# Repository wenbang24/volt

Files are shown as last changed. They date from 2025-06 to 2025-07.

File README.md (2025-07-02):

# Volt
A portable guitar amp that works with your bluetooth device, so you can play anywhere, anytime.

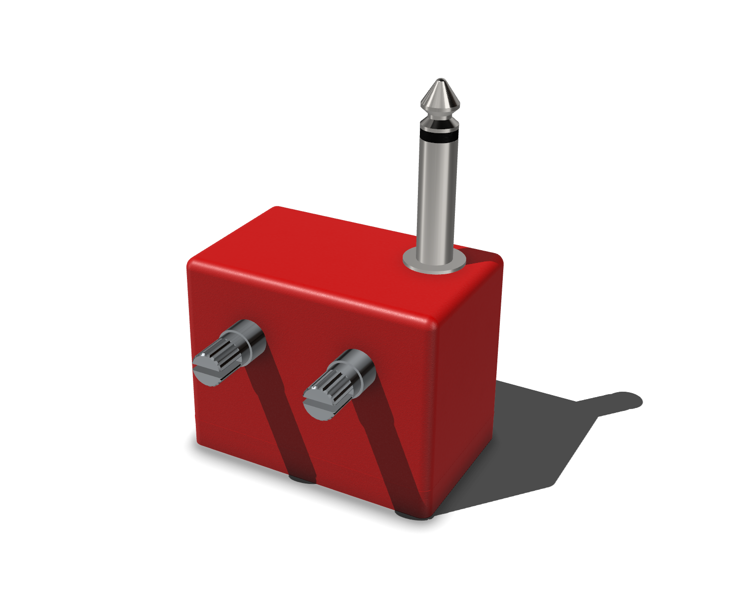
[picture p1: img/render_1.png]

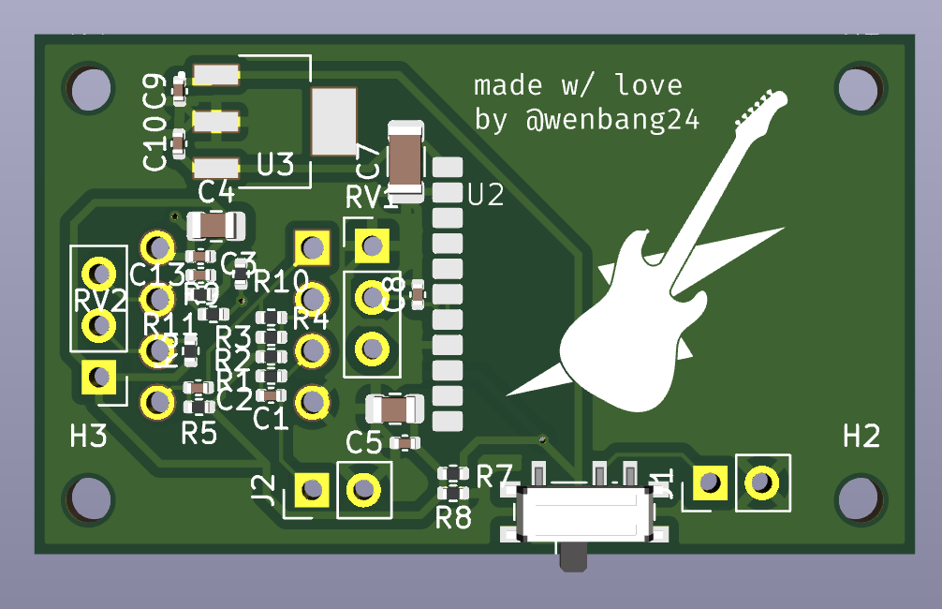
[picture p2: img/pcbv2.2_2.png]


## BOM
|Designator |Footprint |Quantity|Value |LCSC Part #| Link |
|---|---|---|---|---|---|
|C1, C13 |0402 |2 |1u |C14445 |[LCSC](https://lcsc.com/product-detail/Multilayer-Ceramic-Capacitors-MLCC-SMD-SMT_Samsung-Electro-Mechanics-CL05A105KP5NNNC_C14445.html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)|
|C10, C3, C5 |0402 |3 |100n |C1525 |[LCSC](https://lcsc.com/product-detail/Multilayer-Ceramic-Capacitors-MLCC-SMD-SMT_Samsung-Electro-Mechanics-CL05B104KO5NNNC_C1525.html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)|
|C2, C8 |0402 |2 |4u7 |C23733 |[LCSC](https://lcsc.com/product-detail/Multilayer-Ceramic-Capacitors-MLCC-SMD-SMT_Samsung-Electro-Mechanics-CL05A475MP5NRNC_C23733.html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)|
|C4, C6 |0805 |2 |47u |C1954938 |[LCSC](https://lcsc.com/product-detail/Tantalum-Capacitors_Kyocera-AVX-TLJR476M010R3200_C1954938.html?s_z=n_C1954938)|
|C7 |1206 |1 |100u |C883598 |[LCSC](https://lcsc.com/product-detail/Multilayer-Ceramic-Capacitors-MLCC-SMD-SMT_Murata-Electronics-GRM31CR61A107MEA8L_C883598.html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)|
|C9 |0402 |1 |0.22u |C16772 |[LCSC](https://lcsc.com/product-detail/Multilayer-Ceramic-Capacitors-MLCC-SMD-SMT_Samsung-Electro-Mechanics-CL05B224KO5NNNC_C16772.html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)|
|R1 |0402 |1 |1k |C26083 |[LCSC](https://lcsc.com/product-detail/Chip-Resistor-Surface-Mount_UNI-ROYAL-Uniroyal-Elec-0402WGF1004TCE_C26083.html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)|
|R10, R3 |0402 |2 |4k7 |C25900 |[LCSC](https://lcsc.com/product-detail/Chip-Resistor-Surface-Mount_UNI-ROYAL-Uniroyal-Elec-0402WGF4701TCE_C25900.html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)|
|R11, R4, R6 |0402 |3 |10k |C25744 |[LCSC](https://lcsc.com/product-detail/Chip-Resistor-Surface-Mount_UNI-ROYAL-Uniroyal-Elec-0402WGF1002TCE_C25744.html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)|
|R2, R7, R8, R9|0402 |4 |100k |C25741 |[LCSC](https://lcsc.com/product-detail/Chip-Resistor-Surface-Mount_UNI-ROYAL-Uniroyal-Elec-0402WGF1003TCE_C25741.html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)|
|R5 |0402 |1 |220k |C25767 |[LCSC](https://lcsc.com/product-detail/Chip-Resistor-Surface-Mount_UNI-ROYAL-Uniroyal-Elec-0402WGF2203TCE_C25767.html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)|
|SW1 |SW_SPDT_PCM12 |1 |SW_SPDT |C221841 |[LCSC](https://lcsc.com/product-detail/Slide-Switches_C-K-PCM12SMTR_C221841.html?s_z=n_C221841)|
|U3 |VREG_LM7805MP_NOPB|1 |LM7805_TO220|C2848241 |[LCSC](https://lcsc.com/product-detail/Voltage-Regulators-Linear-Low-Drop-Out-LDO-Regulators_Texas-Instruments-LM7805MPX-NOPB_C2848241.html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)|

Price: $6.47
### Parts to source yourself
|Designator |Footprint |Quantity|Value | Link |
|---|---|---|---|---|
|U1|DIP-8|1|TL072|[AliExpress](https://www.aliexpress.com/item/1005006135219871.html?spm=a2g0o.order_list.order_list_main.17.5d4e1802HO5hMP)|
|U2||1|BT 5.3 Audio Transmitter|[AliExpress](https://www.aliexpress.com/item/1005006761214266.html?spm=a2g0o.order_list.order_list_main.35.5d4e1802HO5hMP)|
|J1||1|1/4" Audio Jack|[AliExpress](https://www.aliexpress.com/item/1005006199010497.html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)|
|J2||1|9V Battery Connector|[AliExpress](https://www.aliexpress.com/item/1005003688602261.html?spm=a2g0o.order_list.order_list_main.23.531a1802qO4r9D)|
|RV1||1|100k Potentiometer (logarithmic)|[Core Electronics](https://core-electronics.com.au/rotary-potentiometer-100k-ohm-logarithmic-panel-mount.html)|
|RV2||1|100k Potentiometer (linear)|[Core Electronics](https://core-electronics.com.au/rotary-potentiometer-100k-ohm-linear-panel-mount.html)|
|||4|M2 Screws|[AliExpress](https://www.aliexpress.com/item/4000970993800.html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)|

Price: $16.57

Also:
- 9V Battery
- Case (files in `case/`)
- Some wires & solder

Total PCB & PCBA Price: $32.51

Total Price: $49.08

**Total Price + est. shipping**: $60.00

(prices converted from AUD to USD, accurate as of 2025-06-29)

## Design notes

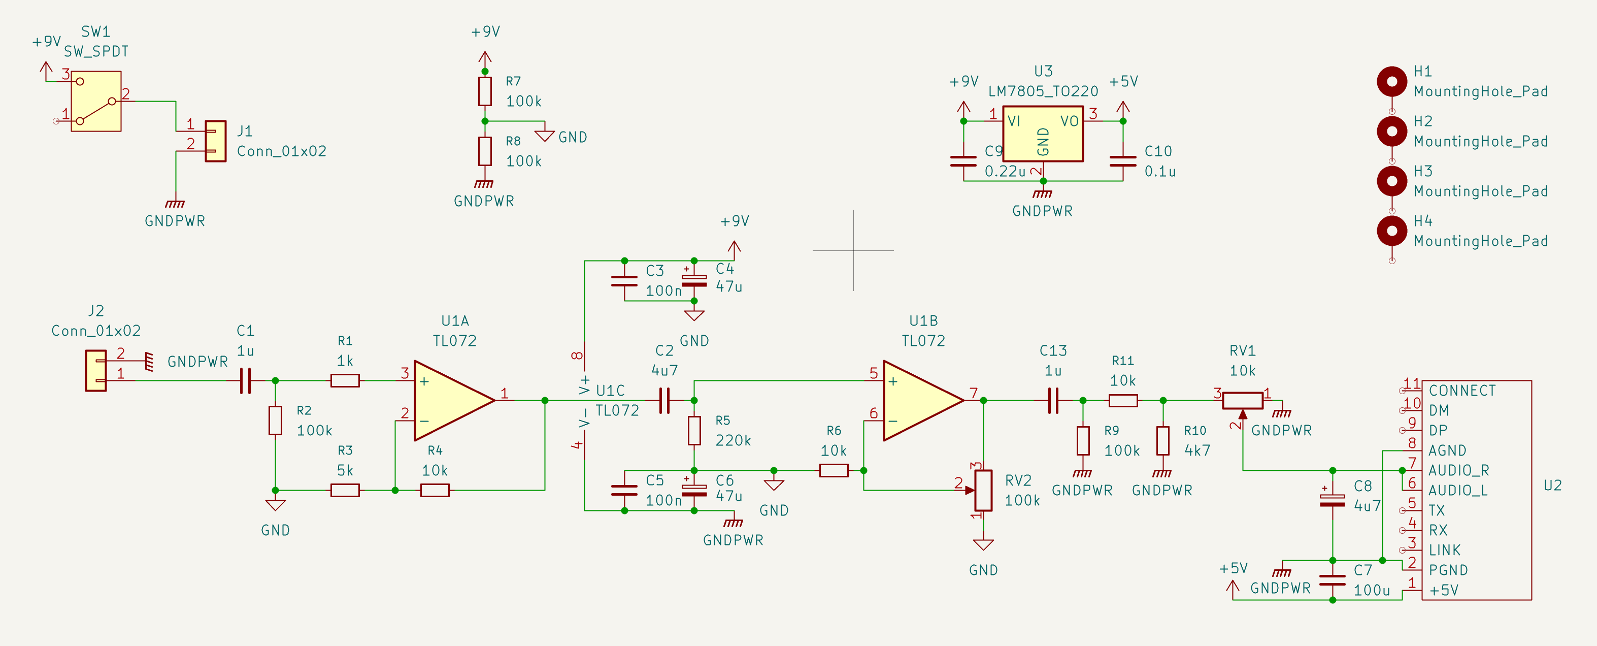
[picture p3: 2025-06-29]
img/schematicv3.png

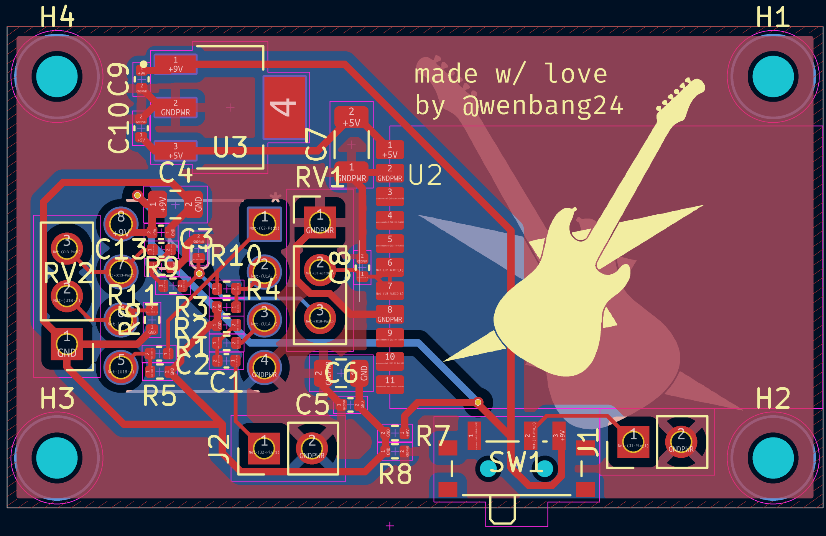
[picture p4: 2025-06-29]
img/pcbv2.2_3.png

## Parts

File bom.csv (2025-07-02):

Designator | Footprint | Quantity | Value | LCSC Part # | Link
C1, C13 | 0402 | 2 | 1u | C14445 | https://lcsc.com/product-detail/Multilayer-Ceramic-Capacitors-MLCC-SMD-SMT_Samsung-Electro-Mechanics-CL05A105KP5NNNC_C14445.html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
C10, C3, C5 | 0402 | 3 | 100n | C1525 | https://lcsc.com/product-detail/Multilayer-Ceramic-Capacitors-MLCC-SMD-SMT_Samsung-Electro-Mechanics-CL05B104KO5NNNC_C1525.html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
C2, C8 | 0402 | 2 | 4u7 | C23733 | https://lcsc.com/product-detail/Multilayer-Ceramic-Capacitors-MLCC-SMD-SMT_Samsung-Electro-Mechanics-CL05A475MP5NRNC_C23733.html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
C4, C6 | 0805 | 2 | 47u | C1954938 | https://lcsc.com/product-detail/Tantalum-Capacitors_Kyocera-AVX-TLJR476M010R3200_C1954938.html?s_z=n_C1954938
C7 | 1206 | 1 | 100u | C883598 | https://lcsc.com/product-detail/Multilayer-Ceramic-Capacitors-MLCC-SMD-SMT_Murata-Electronics-GRM31CR61A107MEA8L_C883598.html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
C9 | 0402 | 1 | 0.22u | C16772 | https://lcsc.com/product-detail/Multilayer-Ceramic-Capacitors-MLCC-SMD-SMT_Samsung-Electro-Mechanics-CL05B224KO5NNNC_C16772.html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
R1 | 0402 | 1 | 1k | C26083 | https://lcsc.com/product-detail/Chip-Resistor-Surface-Mount_UNI-ROYAL-Uniroyal-Elec-0402WGF1004TCE_C26083.html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
R10, R3 | 0402 | 2 | 4k7 | C25900 | https://lcsc.com/product-detail/Chip-Resistor-Surface-Mount_UNI-ROYAL-Uniroyal-Elec-0402WGF4701TCE_C25900.html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
R11, R4, R6 | 0402 | 3 | 10k | C25744 | https://lcsc.com/product-detail/Chip-Resistor-Surface-Mount_UNI-ROYAL-Uniroyal-Elec-0402WGF1002TCE_C25744.html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
R2, R7, R8, R9 | 0402 | 4 | 100k | C25741 | https://lcsc.com/product-detail/Chip-Resistor-Surface-Mount_UNI-ROYAL-Uniroyal-Elec-0402WGF1003TCE_C25741.html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
R5 | 0402 | 1 | 220k | C25767 | https://lcsc.com/product-detail/Chip-Resistor-Surface-Mount_UNI-ROYAL-Uniroyal-Elec-0402WGF2203TCE_C25767.html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
SW1 | SW_SPDT_PCM12 | 1 | SW_SPDT | C221841 | https://lcsc.com/product-detail/Slide-Switches_C-K-PCM12SMTR_C221841.html?s_z=n_C221841
U3 | VREG_LM7805MP_NOPB | 1 | LM7805_TO220 | C2848241 | https://lcsc.com/product-detail/Voltage-Regulators-Linear-Low-Drop-Out-LDO-Regulators_Texas-Instruments-LM7805MPX-NOPB_C2848241.html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
U1 | DIP-8 | 1 | TL072 |  | https://www.aliexpress.com/item/1005006135219871.html
U2 |  | 1 | BT 5.3 Audio Transmitter |  | https://www.aliexpress.com/item/1005006761214266.html
J1 |  | 1 | 1/4" Audio Jack |  | https://www.aliexpress.com/item/1005006199010497.html?sourceType=1
J2 |  | 1 | 9V Battery Connector |  | https://www.aliexpress.com/item/1005003688602261.html
RV1 |  | 1 | 100k Potentiometer (logarithmic) |  | https://core-electronics.com.au/rotary-potentiometer-100k-ohm-logarithmic-panel-mount.html
RV2 |  | 1 | 100k Potentiometer (linear) |  | https://core-electronics.com.au/rotary-potentiometer-100k-ohm-linear-panel-mount.html
 |  | 4 | M2 Screw |  | https://www.aliexpress.com/item/4000970993800.html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

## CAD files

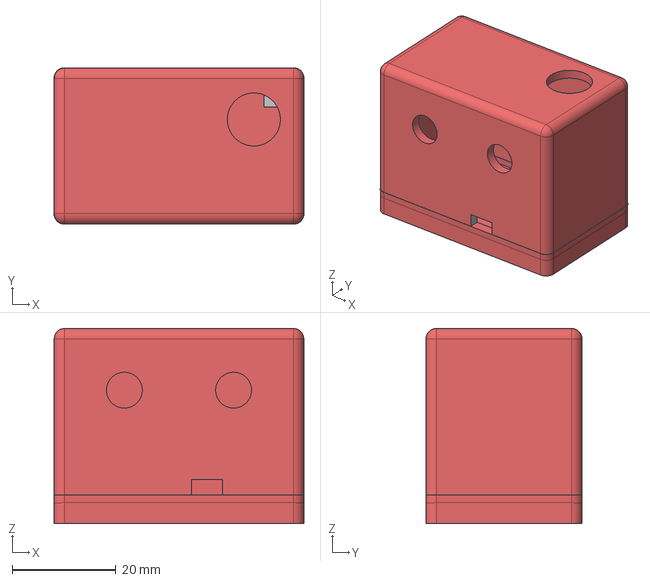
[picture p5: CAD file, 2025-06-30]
case/volt.step
48.1 x 30.1 x 37.5 mm

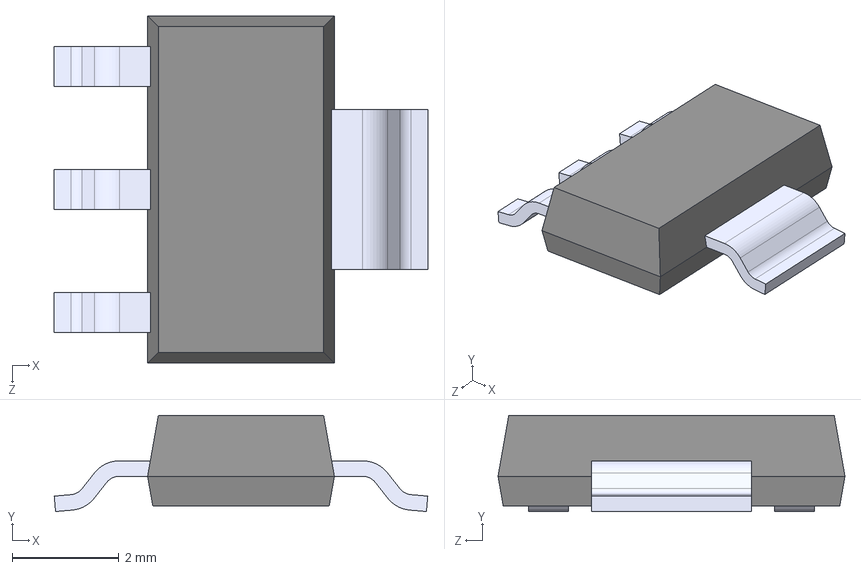
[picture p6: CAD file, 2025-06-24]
pcb/LM7805MP_NOPB/LM7805MP_NOPB.step
7.00 x 1.80 x 6.50 mm

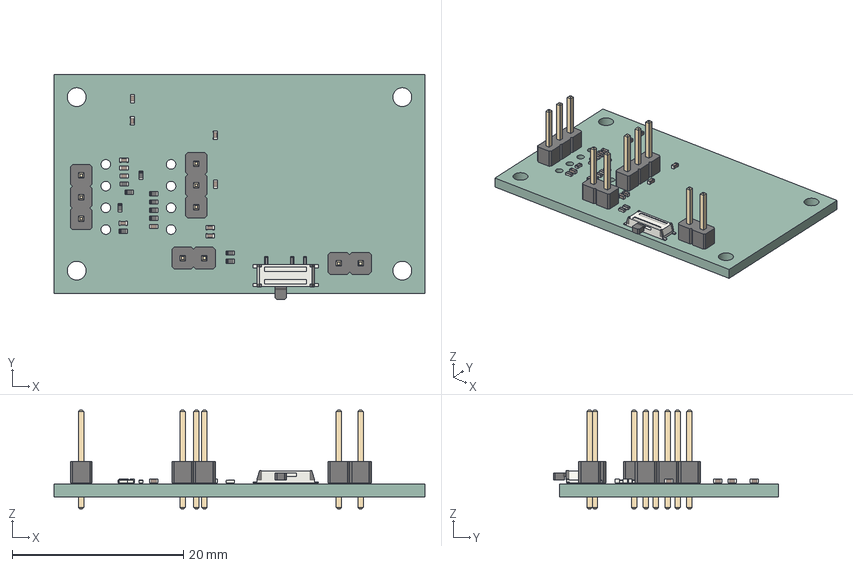
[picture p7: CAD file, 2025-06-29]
pcb/pcb.step
43.4 x 26.3 x 11.5 mm
C_0402_1005Metric x 11
R_0402_1005Metric x 11
PinHeader_1x03_P2.54mm_Vertical x 2
SW_SPDT_PCM12
PinHeader_1x02_P2.54mm_Vertical x 2
pcb_PCB

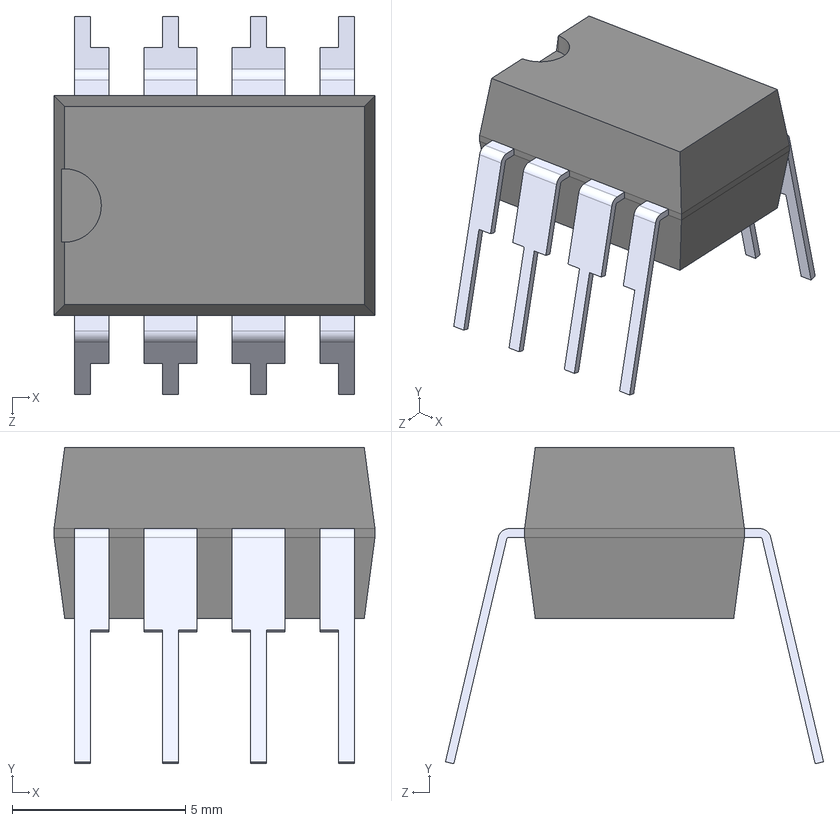
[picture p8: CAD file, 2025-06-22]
pcb/TL072CN/TL072CN.step
9.27 x 9.14 x 10.9 mm

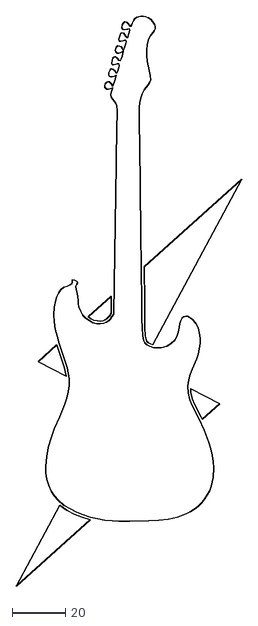
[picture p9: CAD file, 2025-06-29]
volt.dxf
84.9 x 215.1

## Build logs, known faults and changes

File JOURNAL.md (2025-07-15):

---
title: "Volt"
author: "Ben Wang"
description: "A bluetooth guitar amp for portable playing"
created_at: "2025-06-17"
---

total time (so far): 47.5 hrs

## 2025-06-17
- Researched how guitar amps work
- Researched components needed for a guitar amp
- Researched how bluetooth works

Time spent: 2 hrs

## 2025-06-18
- Found specific components to use
- Made symbols & footprints for the components
- Started researching how to make an amplifier circuit

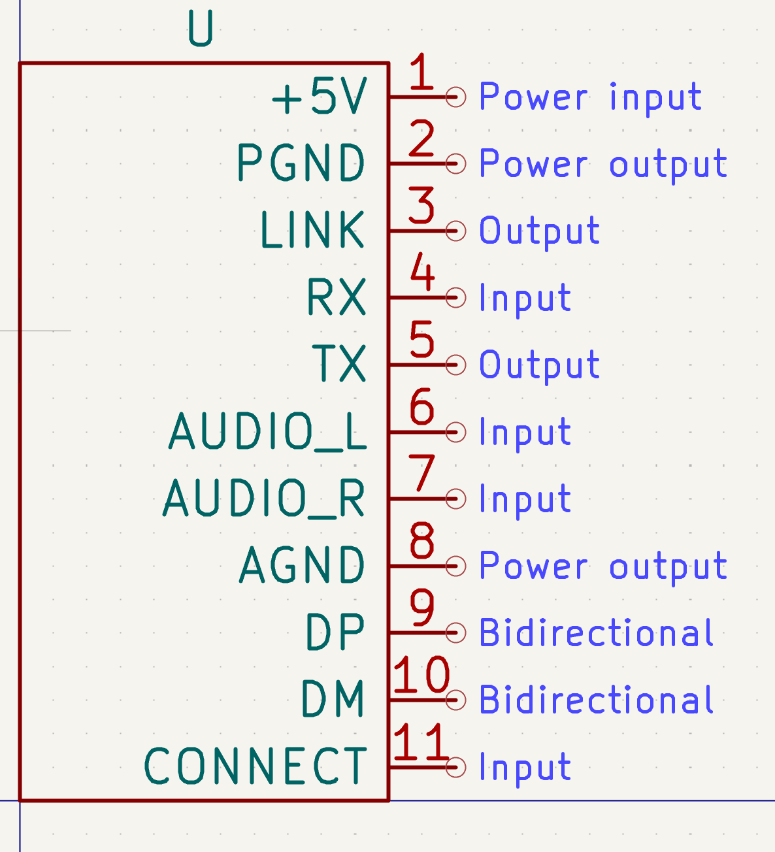
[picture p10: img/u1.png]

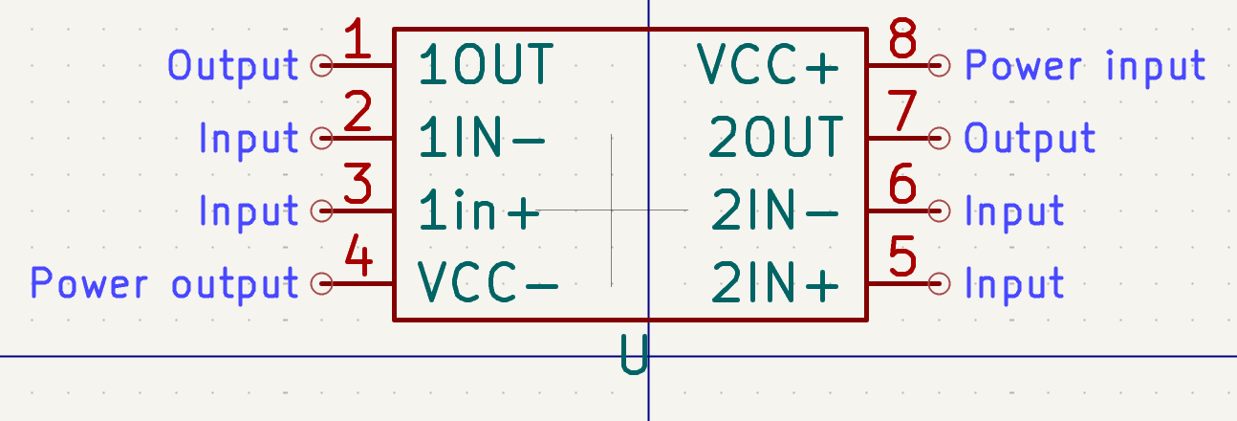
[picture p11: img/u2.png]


Time spent: 3 hrs

## 2025-06-21
- Fixed pin orientation of bluetooth module
- Made v1 of schematic (partial reference design [here](https://2.bp.blogspot.com/-1wqxx-jvaGM/V-nGi2WOsvI/AAAAAAAAA0s/gCCoJ27efYsKQ02fjROY2QzsP2jolWZbACLcB/s1600/HiFi%2BPreAmp%2BCircuit%2BSchematic.jpg))

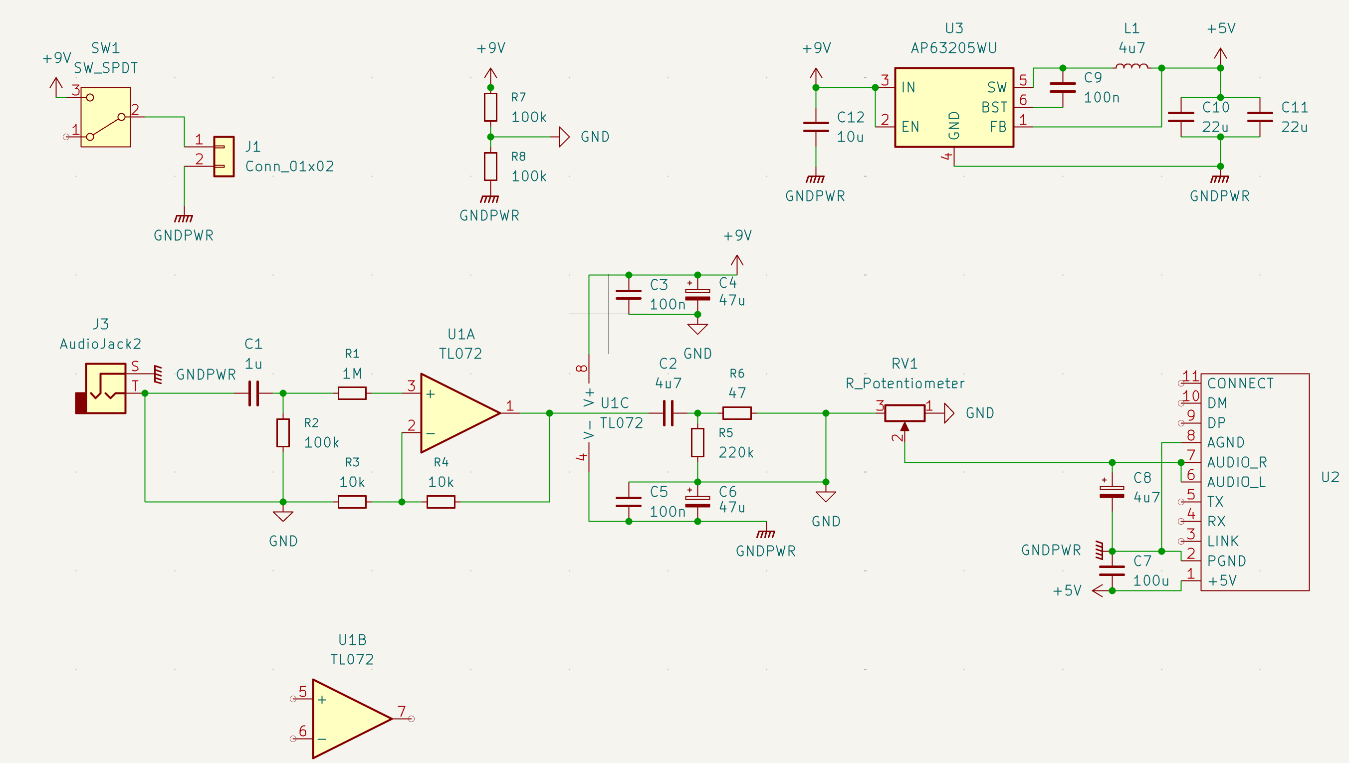
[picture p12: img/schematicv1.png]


Time spent: 7 hrs (yeah it was not easy :|)

## 2025-06-21
- Footprints, footprints, footprints
- First draft of PCB (awaiting review)
- Minor edits to schematic

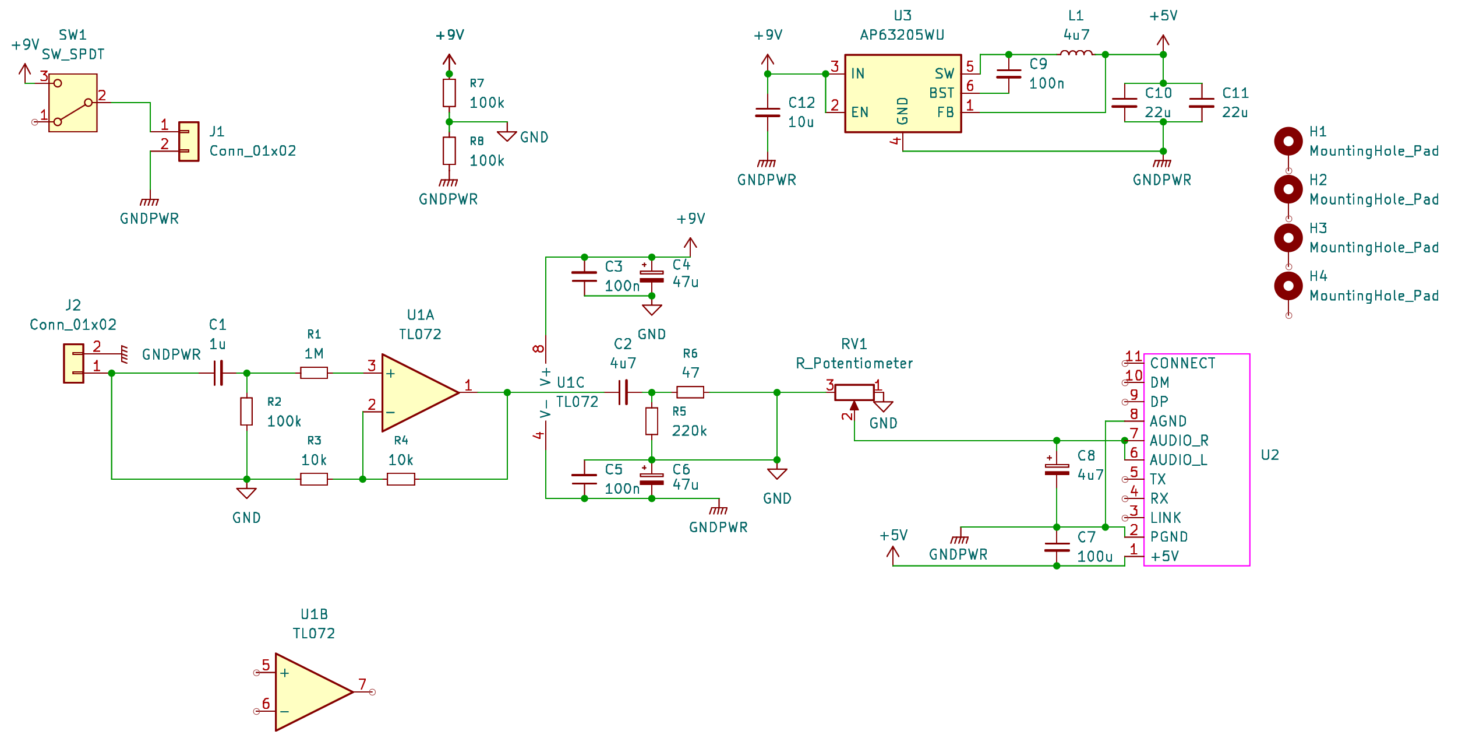
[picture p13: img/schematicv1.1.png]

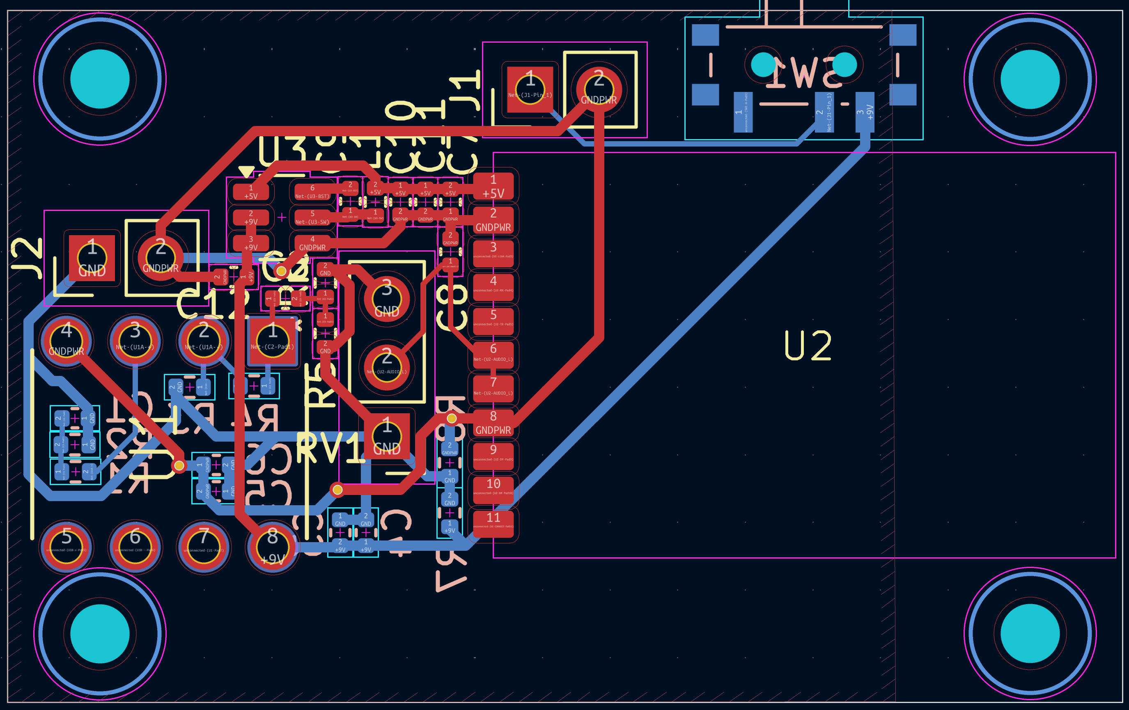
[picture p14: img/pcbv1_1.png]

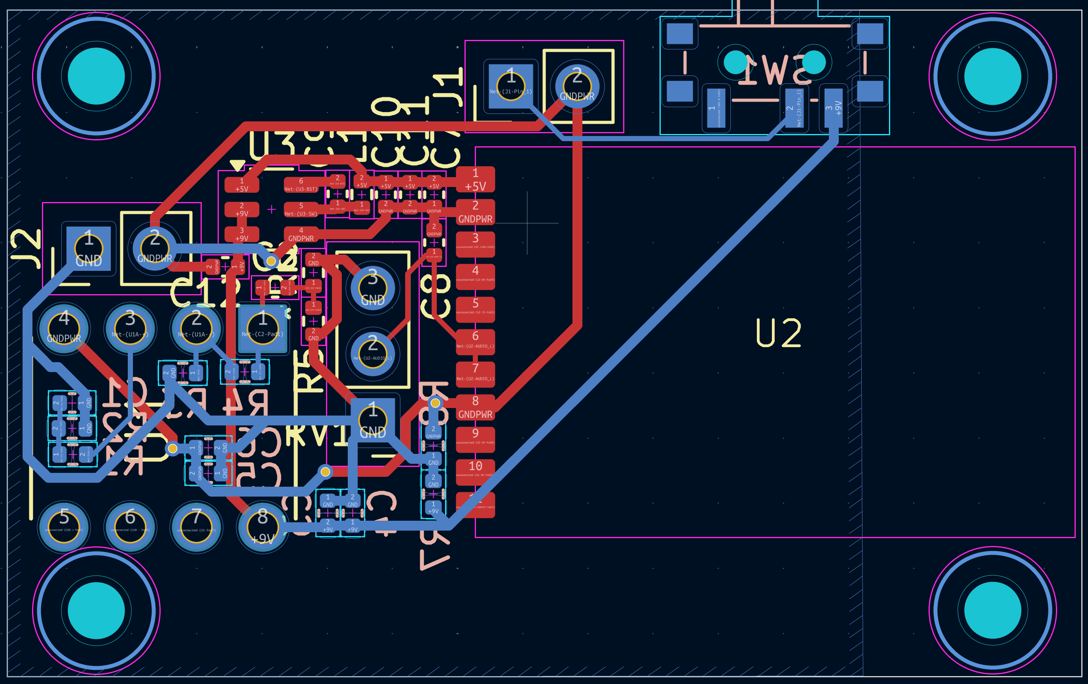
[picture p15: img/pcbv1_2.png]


Time spent: 5 hrs

## 2025-06-22
- Added distortion circuit
- Started figuring out how SPICE simulations work

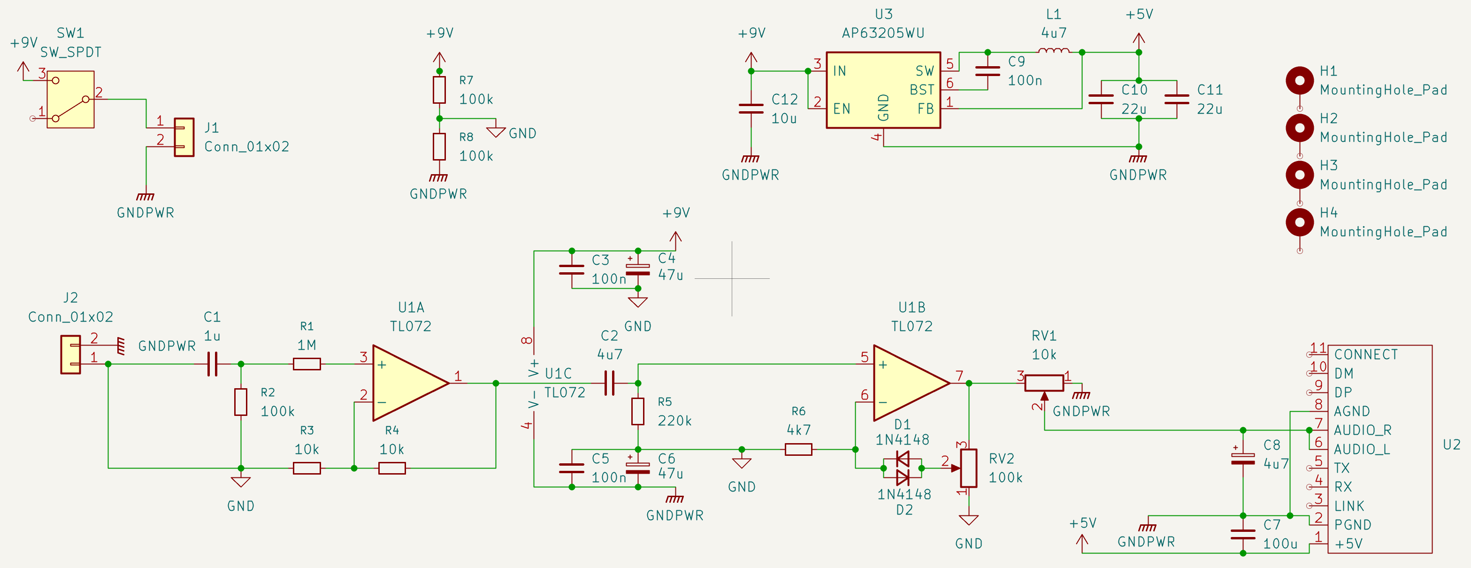
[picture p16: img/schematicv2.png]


Time spent: 4 hrs

## 2025-06-23
- Installed LTSpice
- Built the circuit in LTSpice
- Simulated the circuit
- Tried a lot of different values for the components
- Added an RC filter to the output
- Still not working :|

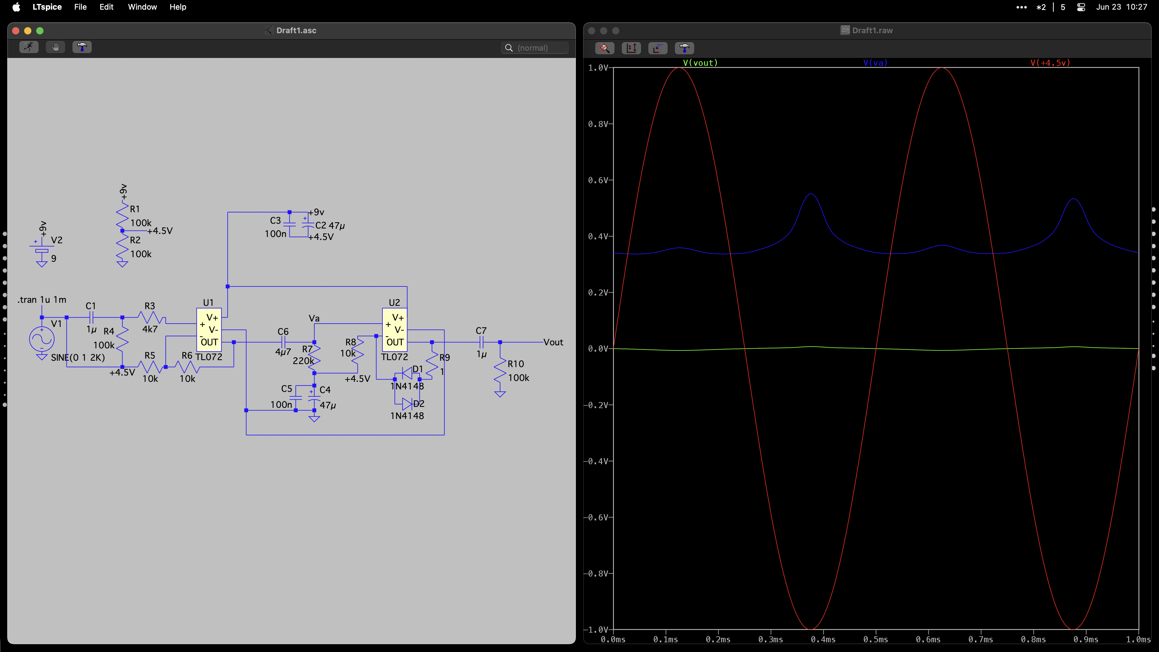
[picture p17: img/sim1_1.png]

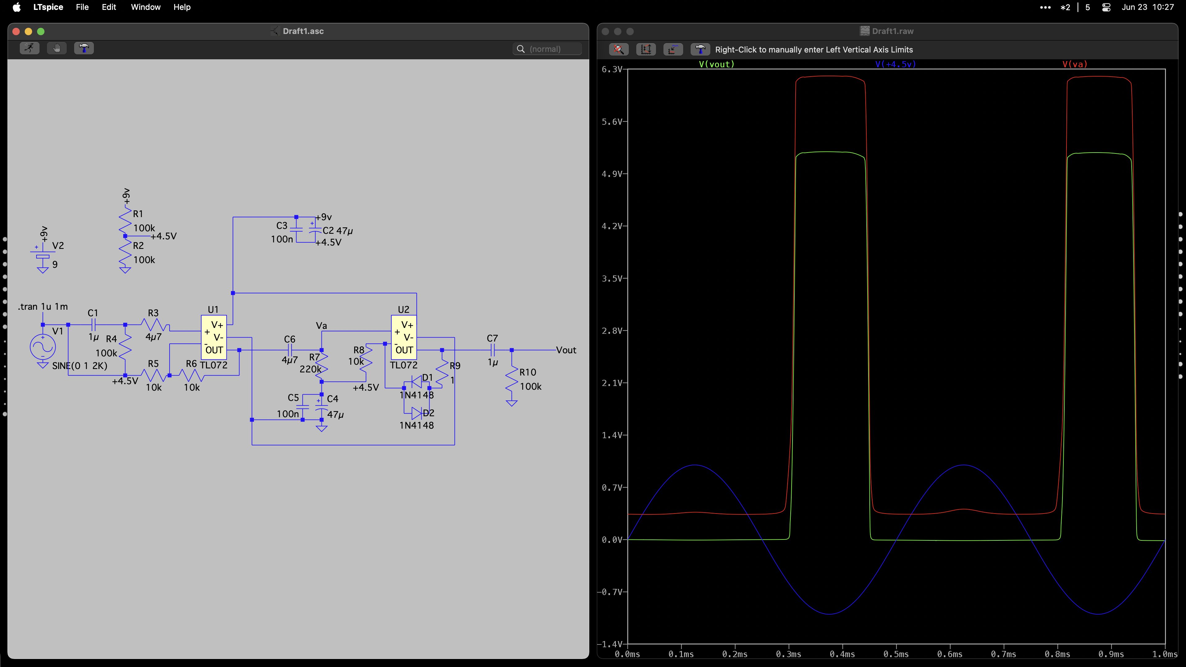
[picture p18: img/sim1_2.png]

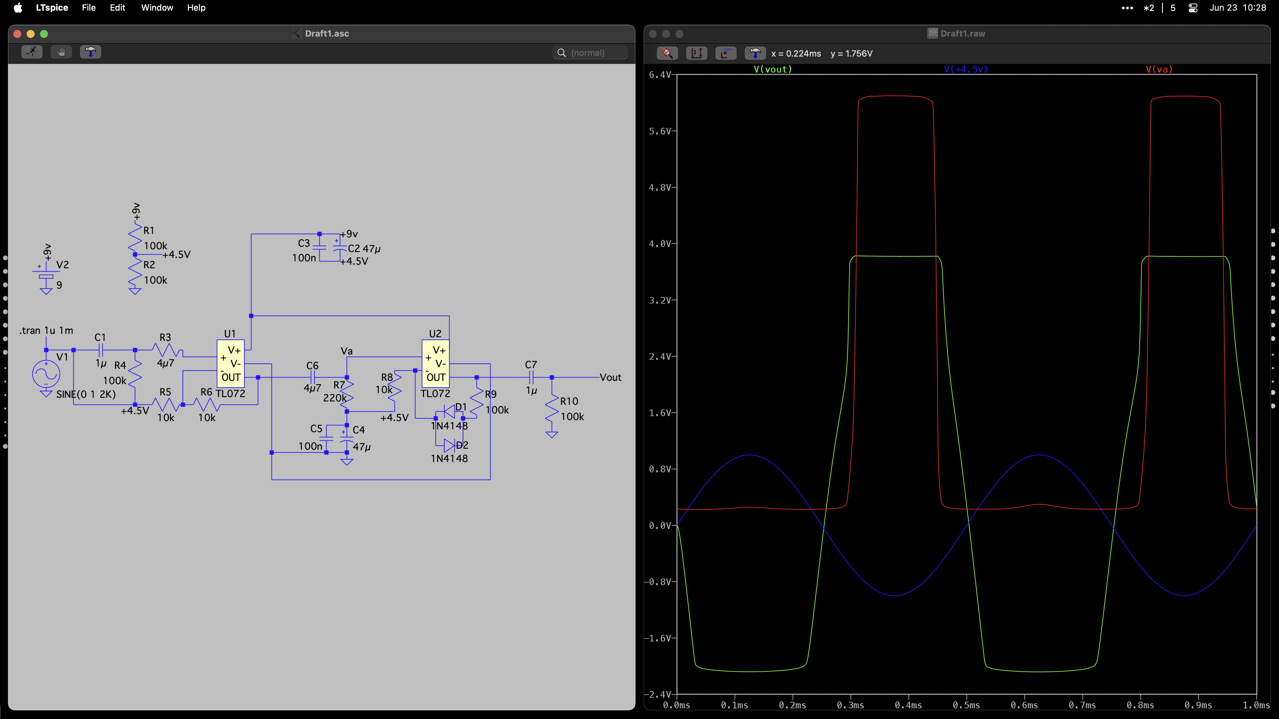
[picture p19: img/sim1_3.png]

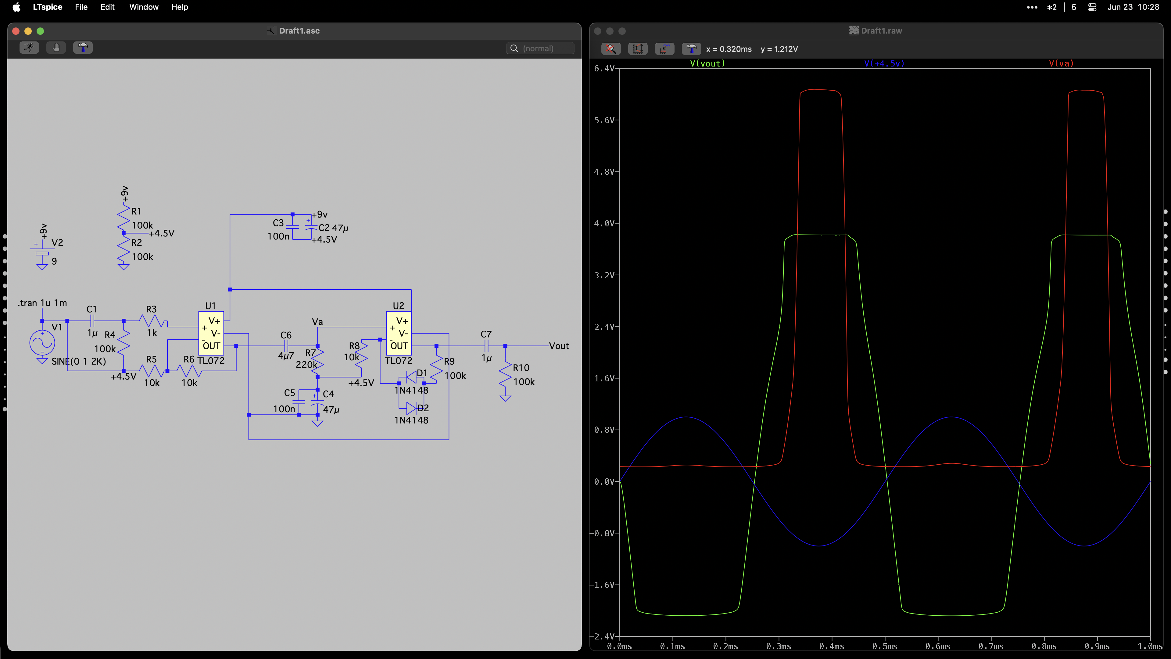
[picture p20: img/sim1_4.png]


Time spent: 6 hrs

## 2025-06-24
- Fixed distortion circuit
- Changed pre-amp stage
- Added voltage cap (max ~1.9VPP now)
- Changed to LDO for 9V to 5V conversion
- Rebuilt schematic in KiCad
- Researched some parts
- Added TRRS jack for headphone output

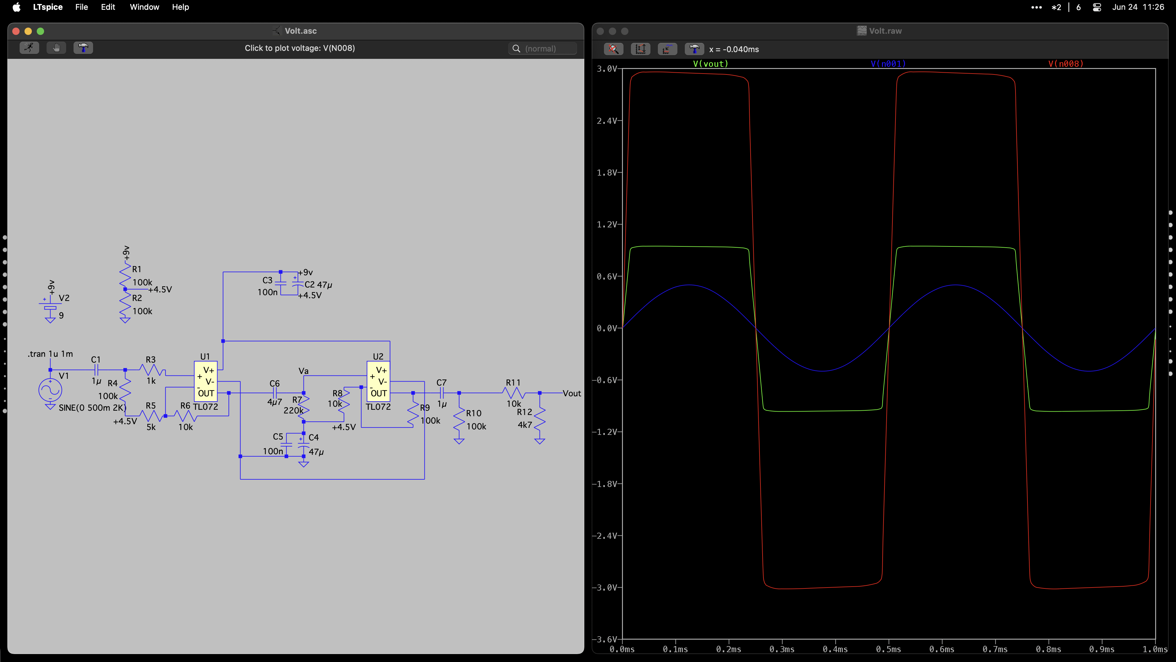
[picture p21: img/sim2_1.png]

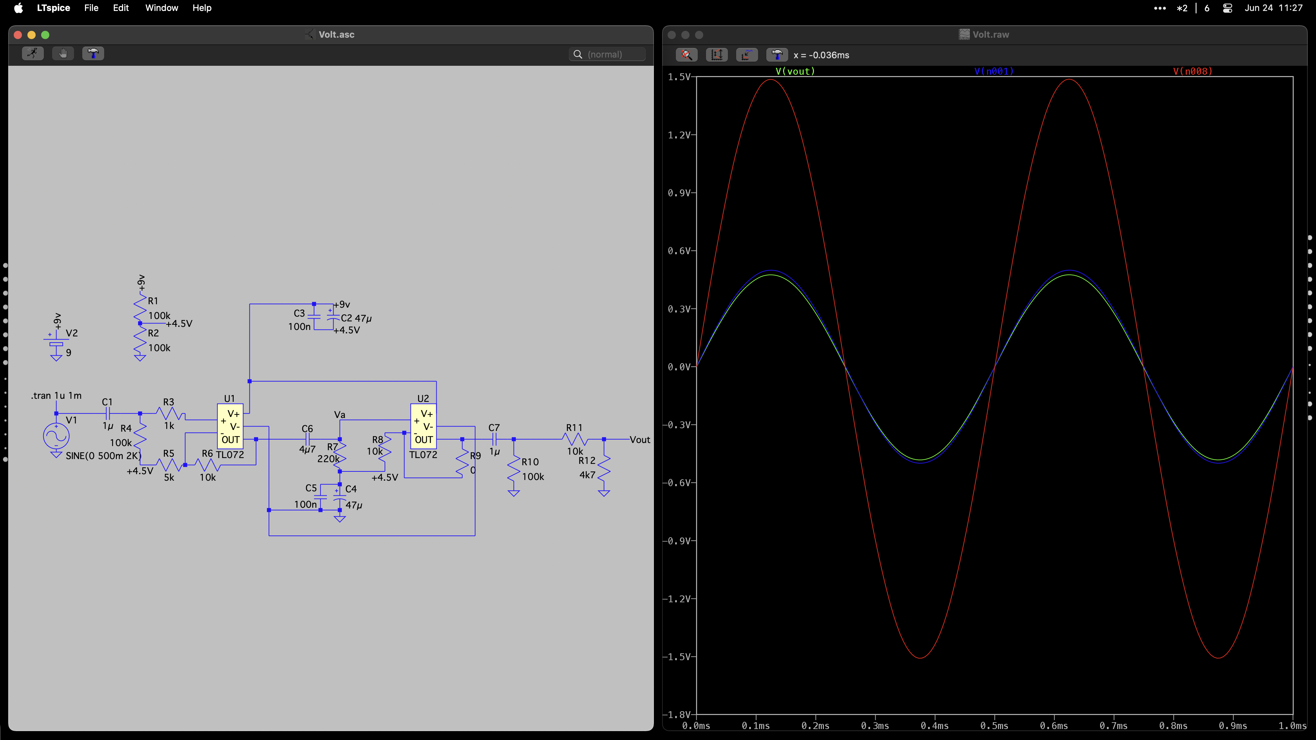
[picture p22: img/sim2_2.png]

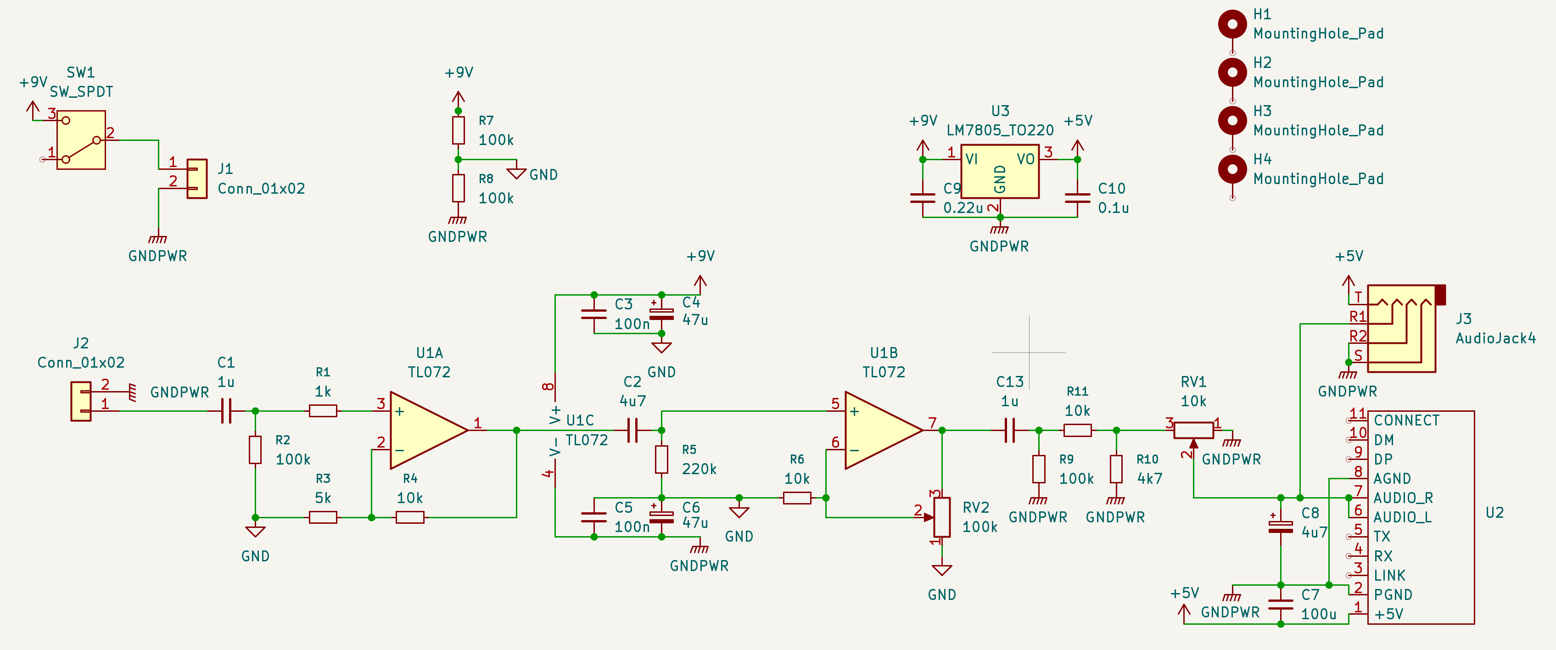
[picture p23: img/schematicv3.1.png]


Time spent: 7 hrs

## 2025-06-26 & 2025-06-29
(i went to Sydney for two days and forgot to journal but i came back and locked in)
- Set up Windows LTSpice using Wine
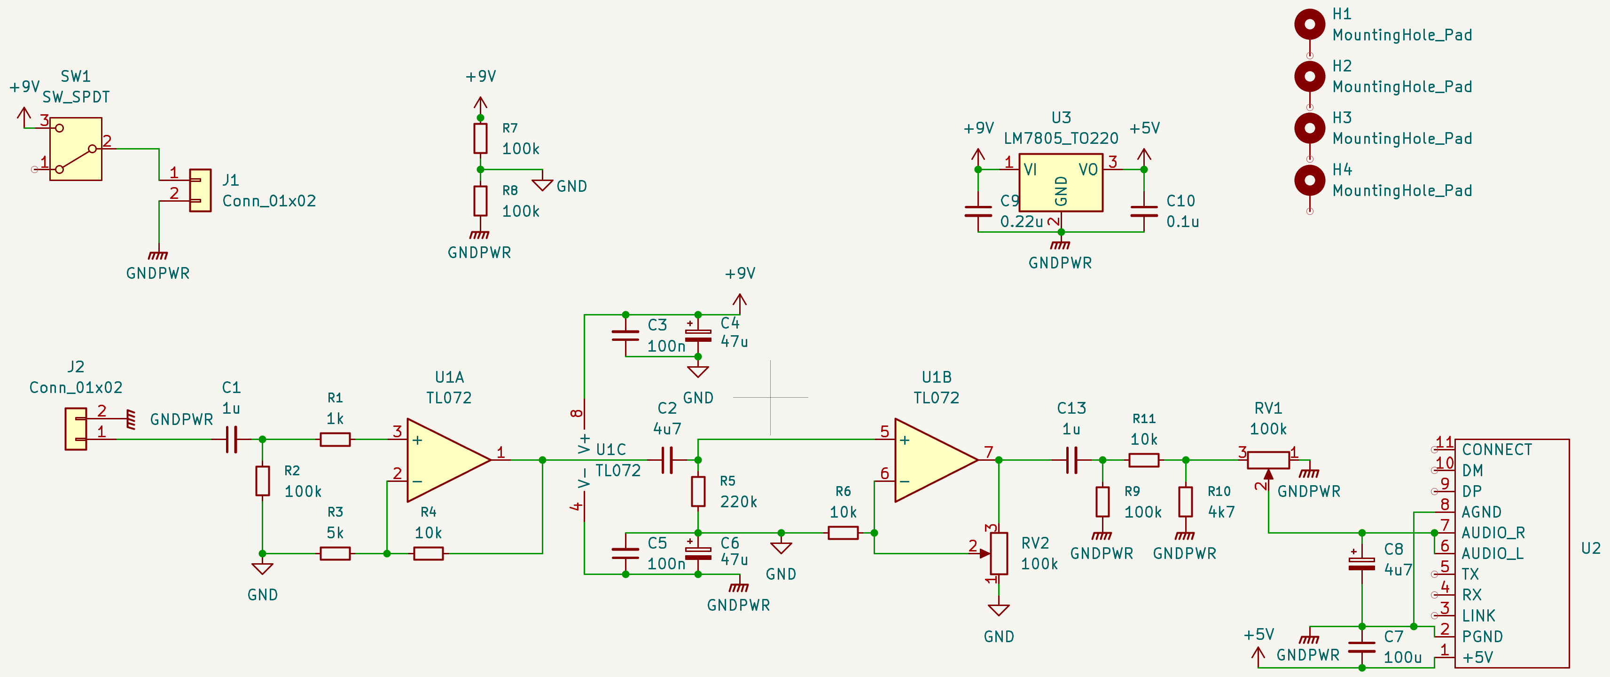
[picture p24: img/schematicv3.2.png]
- Small changes to schematic 
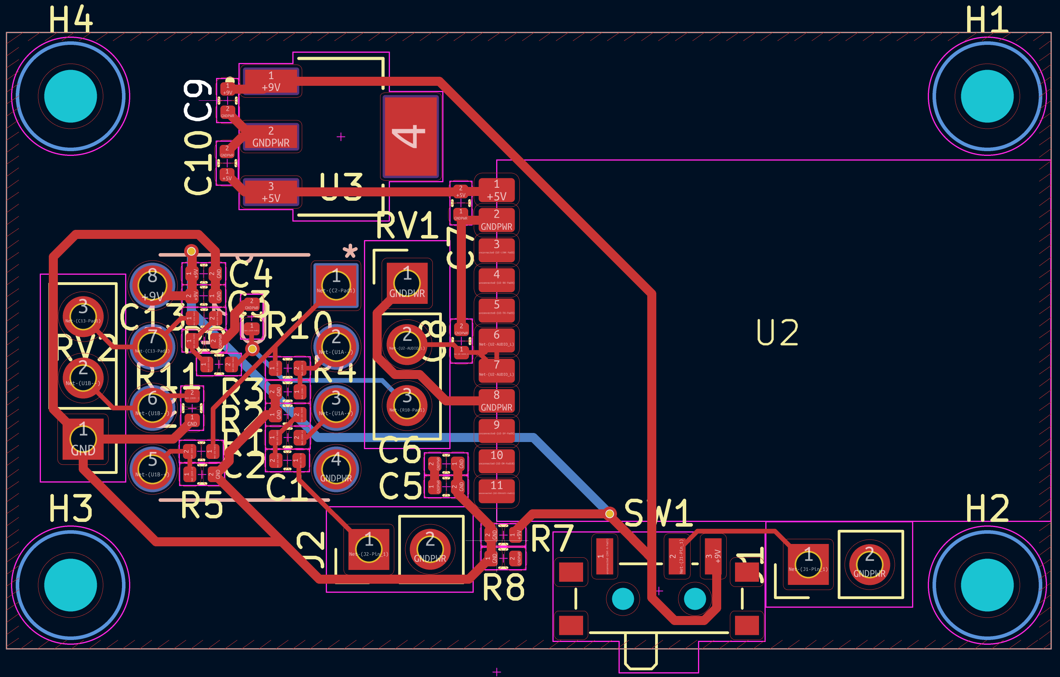
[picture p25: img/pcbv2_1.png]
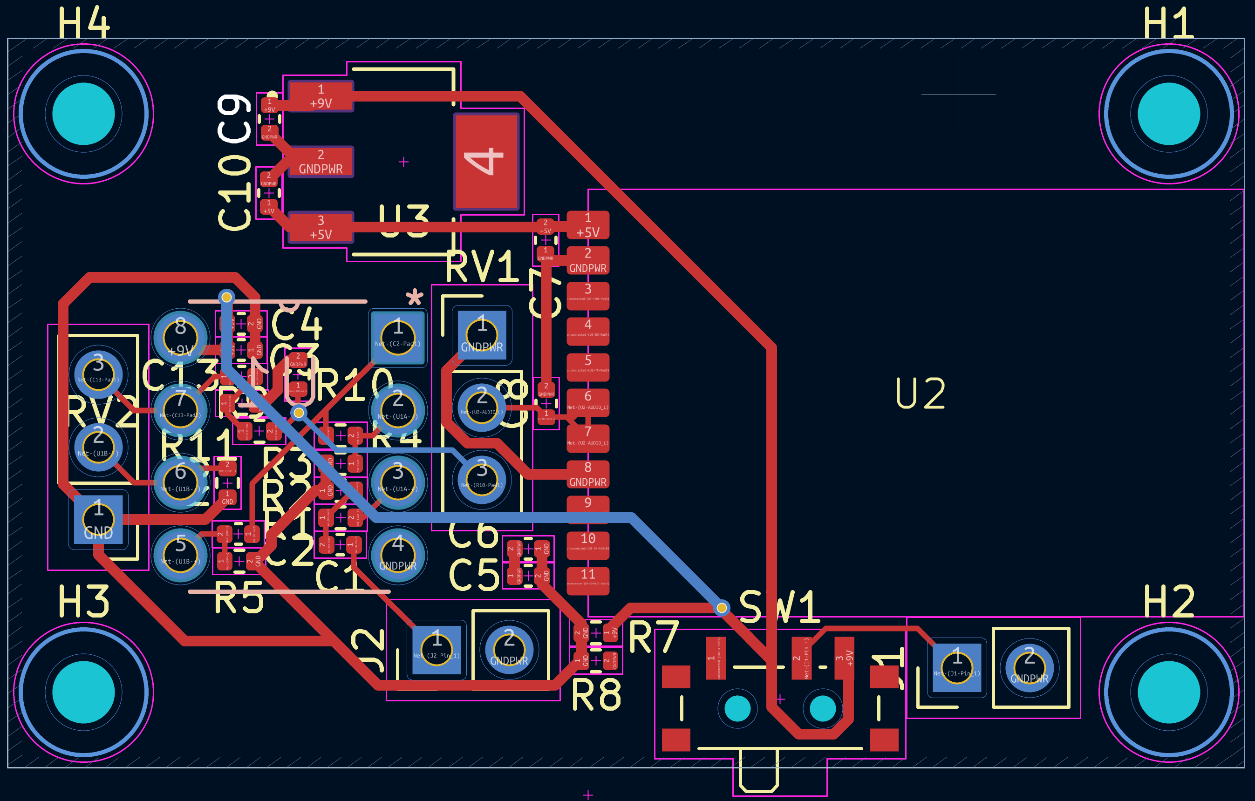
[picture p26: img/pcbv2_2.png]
- Routed PCB  
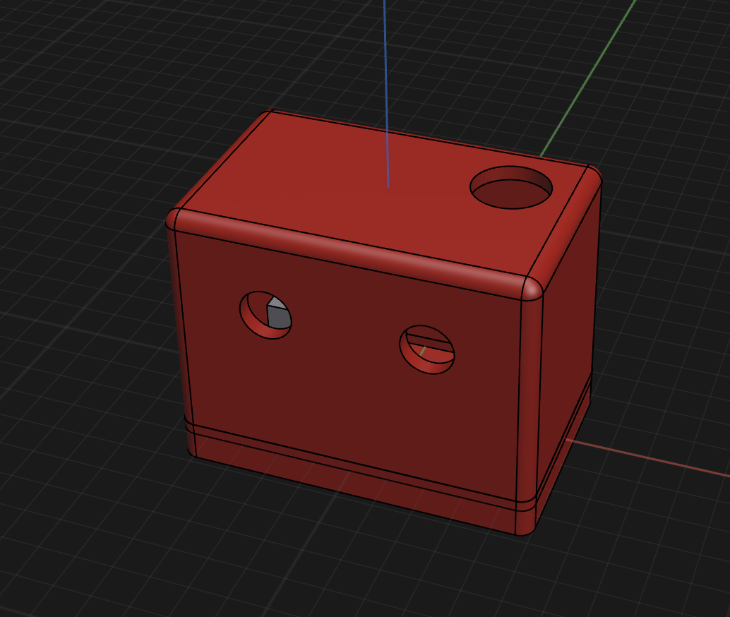
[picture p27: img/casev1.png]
- Made case (its so cool that you can import an image, resize it, and trace it to model parts lol) 
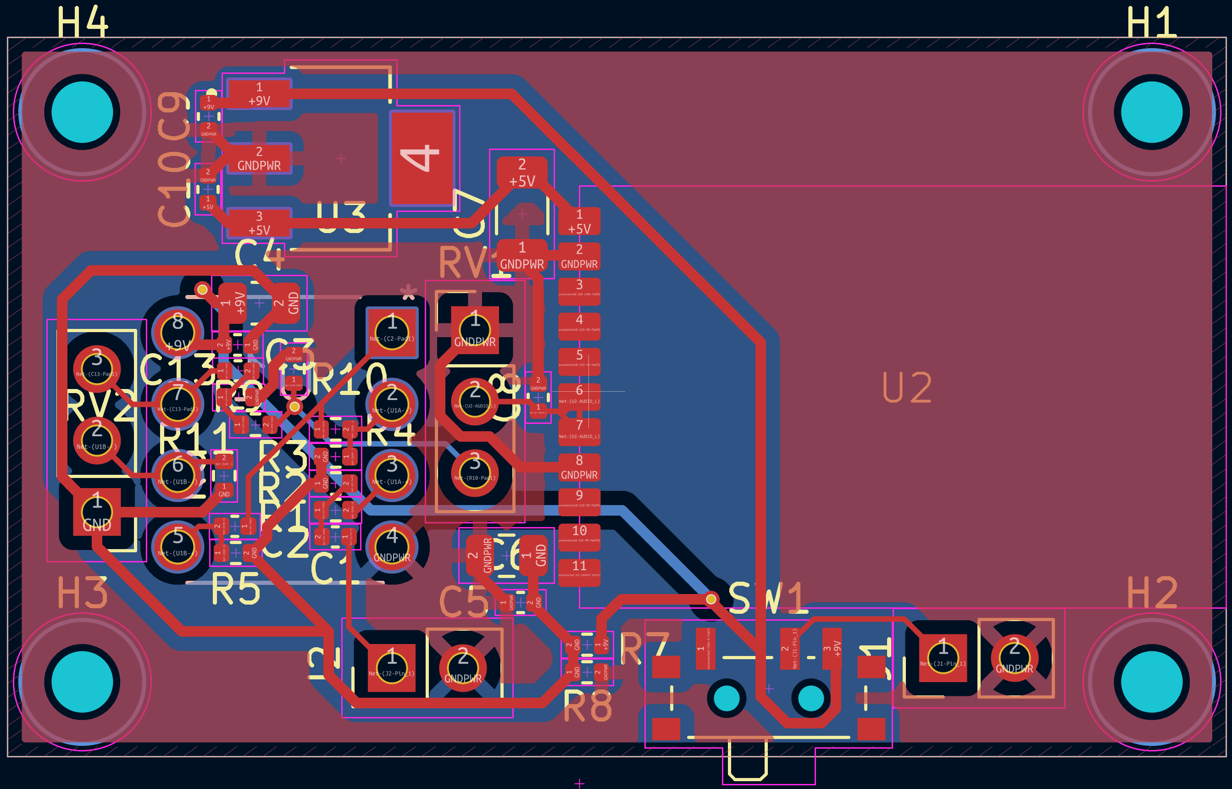
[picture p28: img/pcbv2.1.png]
- Changed some capacitor footprints to obey the laws of physics 
- Made BOM and selected components from LCSC
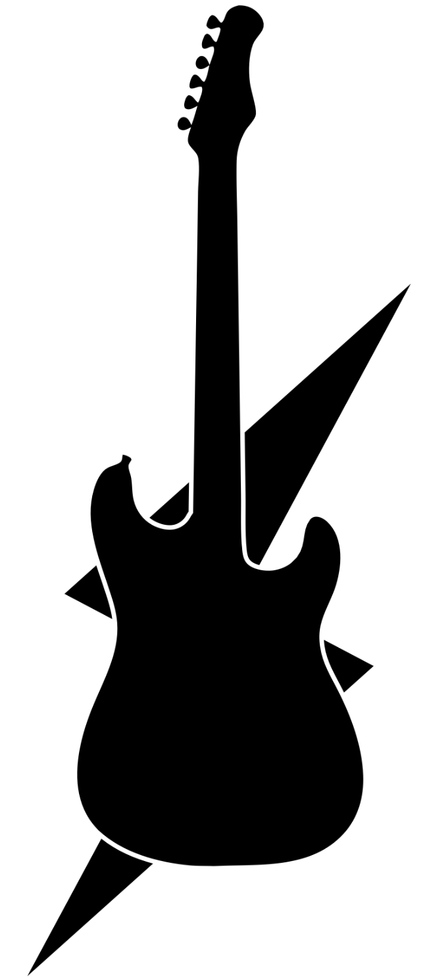
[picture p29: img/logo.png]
- Made logo 
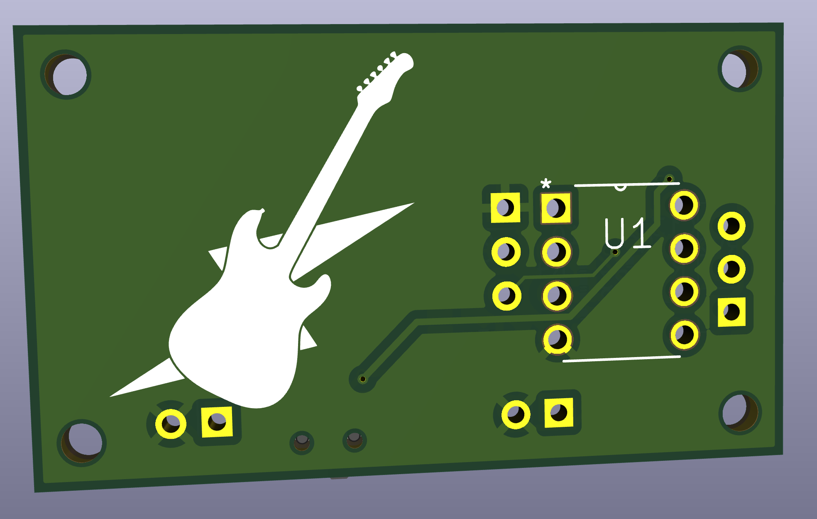
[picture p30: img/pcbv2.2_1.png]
- Added silkscreen art  
- Rendered case 

Time spent: 13 hrs

## 2025-07-02
- Added links to BOM

Time spent: 30 mins

## 2025-07-03
- Added connect button breakout
- Bought stuff

Time spent: 1 hr

## 2025-07-15
- Parts are here!
- Soldered the PCB
- Modded the TS connector to fit my guitar because the output socket is inset into the body (first time dealing with sparks lmao)
- It connects to my computer but no audio comes through :(, yet to connect it to a speaker (how do i even do that)



Time spent: 4 hrs

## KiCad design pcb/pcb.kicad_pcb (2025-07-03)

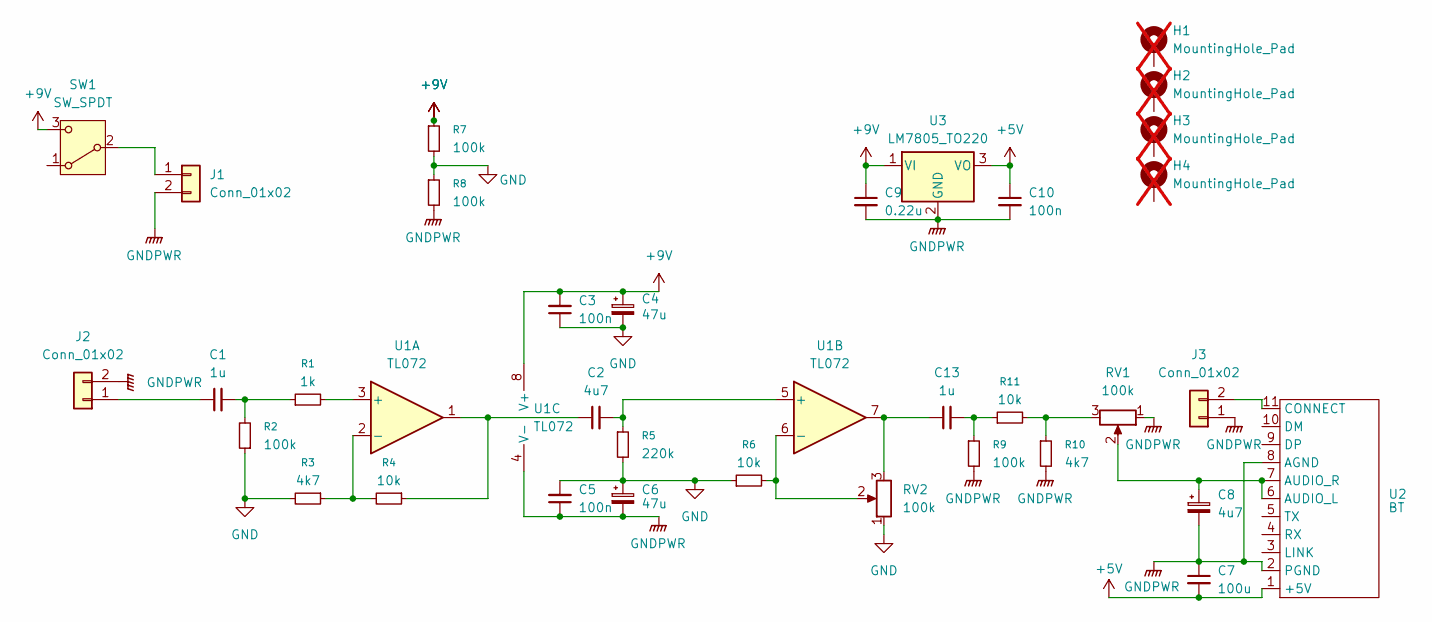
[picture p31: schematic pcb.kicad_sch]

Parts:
C1, C13: 1u; C_0402_1005Metric; LCSC C14445
C2, C8: 4u7; C_0402_1005Metric; LCSC C23733
C3, C5, C10: 100n; C_0402_1005Metric; LCSC C1525
C4, C6: 47u; C_0805_2012Metric; LCSC C1954938
C7: 100u; C_1206_3216Metric; LCSC C883598
C9: 0.22u; C_0402_1005Metric; LCSC C16772
H1, H2, H3, H4: MountingHole_Pad; MountingHole_2.2mm_M2; not fitted
J1, J2, J3: Conn_01x02; PinHeader_1x02_P2.54mm_Vertical
R1: 1k; R_0402_1005Metric; LCSC C26083
R2, R7, R8, R9: 100k; R_0402_1005Metric; LCSC C25741
R3, R10: 4k7; R_0402_1005Metric; LCSC C25900
R4, R6, R11: 10k; R_0402_1005Metric; LCSC C25744
R5: 220k; R_0402_1005Metric; LCSC C25767
RV1, RV2: 100k; PinHeader_1x03_P2.54mm_Vertical
SW1: SW_SPDT; SW_SPDT_PCM12; LCSC C221841
U1: TL072; DIP254P762X533-8
U2: BT; BT_Transmitter
U3: LM7805_TO220; VREG_LM7805MP_NOPB; LCSC C2848241

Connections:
+5V: C7.2, C10.1, U2.1 (+5V), U3.3 (VO)
+9V: C3.2, C4.1, C9.1, R7.1, SW1.3 (C), U1.8 (V+), U3.1 (VI)
GND: C3.1, C4.2, C5.2, C6.1, R2.1, R3.2, R5.2, R6.1, R7.2, R8.1, RV2.1
GNDPWR: C5.1, C6.2, C7.1, C8.2, C9.2, C10.2, J1.2, J2.2, J3.1, R8.2, R9.2, R10.2, RV1.1, U1.4 (V-), U2.2 (PGND), U2.8 (AGND), U3.2 (GND)
unnamed: C1.2, R1.1, R2.2
unnamed: C2.1, R4.1, U1.1
unnamed: C13.1, RV2.3, U1.7
unnamed: C13.2, R9.1, R11.1
unnamed: J1.1, SW1.2 (B)
unnamed: C1.1, J2.1
unnamed: J3.2, U2.11 (CONNECT)
unnamed: R10.1, R11.2, RV1.3
unnamed: R1.2, U1.3 (+)
unnamed: R3.1, R4.2, U1.2 (-)
unnamed: C2.2, R5.1, U1.5 (+)
unnamed: R6.2, RV2.2, U1.6 (-)
unnamed: C8.1, RV1.2, U2.6 (AUDIO_L), U2.7 (AUDIO_R)

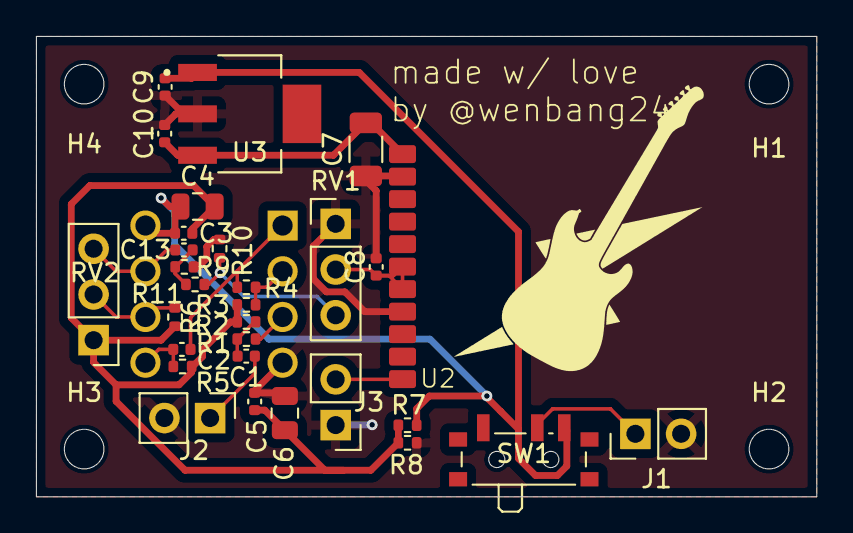
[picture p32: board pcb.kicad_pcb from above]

Board: 2 copper layers, 43.4 x 25.6 mm, 35 parts (1 on the bottom side), 17 nets.

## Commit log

2025-06-18 pcb initial commit
    [pcb.kicad_pcb, pcb.kicad_sch]
2025-06-20 fix pin orientation in symbols
    [pcb.kicad_sch]
2025-06-21 schematic v1
    [pcb.kicad_sch]
2025-06-21 [ImgBot] Optimize images
    *Total -- 354.36kb -> 105.37kb (70.26%)
    /img/schematicv1.png -- 201.20kb -> 52.41kb (73.95%)
    /img/u1.png -- 105.86kb -> 34.79kb (67.14%)
    /img/u2.png -- 47.29kb -> 18.18kb (61.56%)
2025-06-21 small stylistic changes to schematic
    [pcb.kicad_sch]
2025-06-22 footprints, a bit of pcb
    [TL072CN.step, pcb.kicad_pcb, pcb.kicad_sch]
2025-06-22 pcb v1
    [pcb.kicad_pcb, pcb.kicad_sch]
2025-06-23 pcb v2: distortion stage
    [pcb.kicad_sch]
2025-06-23 schematic v2, spicing
2025-06-24 voltage cap
2025-06-24 schematic v3
    [LM7805MP_NOPB.step, pcb.kicad_sch]
2025-06-28 pcb v2
    [pcb.kicad_pcb, pcb.kicad_sch]
2025-06-28 [ImgBot] Optimize images
    *Total -- 12,836.88kb -> 5,361.24kb (58.24%)
    /img/schematicv3.1.png -- 245.01kb -> 63.80kb (73.96%)
    /img/schematicv3.2.png -- 248.29kb -> 65.83kb (73.49%)
    /img/schematicv3.png -- 213.52kb -> 58.49kb (72.61%)
    /img/schematicv2.png -- 219.17kb -> 61.16kb (72.1%)
    /img/sim2_2.png -- 1,557.36kb -> 632.07kb (59.41%)
    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
2025-06-29 case & render
    [pcb.step, volt.step]
2025-06-29 change caps, do bom, reroute, readme, ship, etc
    [bom.csv, designators.csv, pcb.kicad_pcb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]
2025-06-29 logo & silkscreen art
    [designators.csv, pcb.kicad_pcb, volt.dxf]
2025-06-29 add pcb to readme
2025-06-30 on switch hole in case
    [volt.step]
2025-07-02 update bom to table form and include links
    [bom.csv]
2025-07-03 connect button footprint
    [designators.csv, pcb.kicad_pcb, pcb.kicad_sch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]
